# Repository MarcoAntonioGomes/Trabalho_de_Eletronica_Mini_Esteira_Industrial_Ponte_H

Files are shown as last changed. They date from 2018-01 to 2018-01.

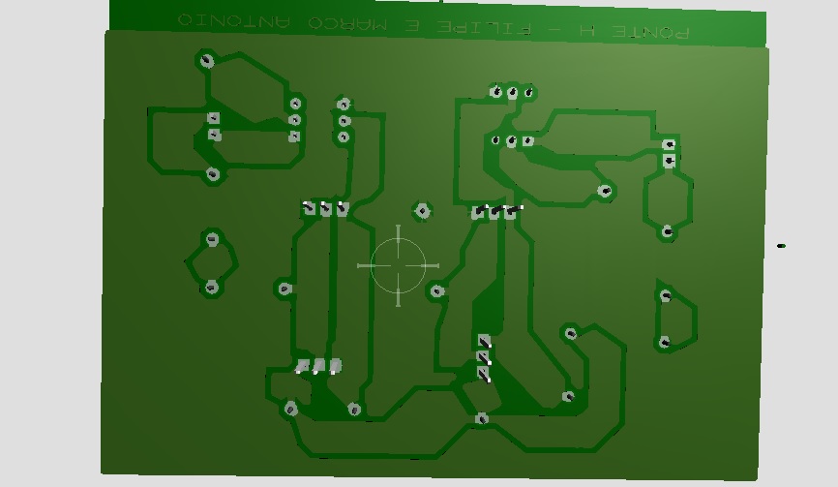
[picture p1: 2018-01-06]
Trilhas 3D.jpg

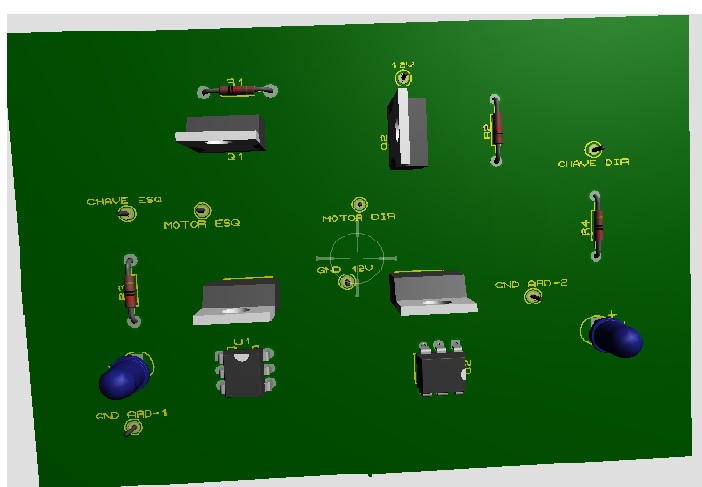
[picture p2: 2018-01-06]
Placa 3D.jpg

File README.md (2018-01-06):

# Trabalho_de_Eletronica_Mini_Esteira_Industrial_Ponte_H
Repositório criado para armazenar os arquivos do Trabalho Final de Eletrônica 2 do curso de Engenharia de Computação - 5º Período - 1º Semestre de 2017 - Confecção de uma Mini Esteira Industrial - com uso de Transistores MOSFETs, Arduíno, placa de circuito impresso, motor dentre outros componentes.

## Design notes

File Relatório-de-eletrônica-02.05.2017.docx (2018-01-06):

O INSTITUTO FEDERAL DE EDUCAÇÃO, CIÊNCIA E TECNOLOGIA DE MINAS GERAIS

FILIPE SOARES,

MARCO AURÉLIO MONTEIRO LIMA

ELETRÔNICA II:

PONTE H

BAMBUÍ

2017

Objetivo:

Verificar experimentalmente o funcionamento da ponte H com motor, utilizando o MOSFET canal N e canal P.

1 – Introdução

Mosfet canal N

MOSFET é um transistor de efeito de Campo de Óxido de Metal Semicondutor.

Figura 1: estrutura simplificada do Mosfet;

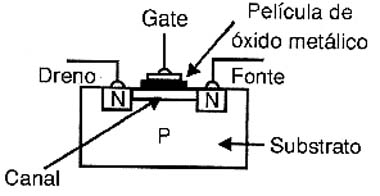
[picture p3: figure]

Uma fina película de óxido de metal isola a região de comporta da região do canal que liga o dreno à fonte. Dependendo da polaridade dos materiais semicondutores podemos ter MOSFET de canais N ou P, conforme a figura 2.

Figura 2: Tipos de MOSFET;

Para usar o transistor de efeito de campo de canal N o circuito básico é mostrado na figura 3.

Figura 3: configuração básica e características do mosfet canal n;

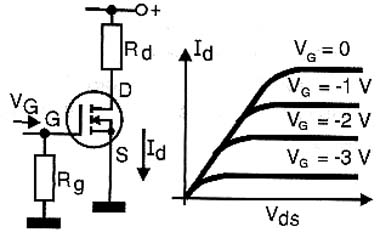
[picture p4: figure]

Com uma tensão nula de comporta a corrente de dreno tem um valor que depende da tensão de alimentação até o ponto de saturação. Para cortar a corrente de dreno a comporta deve ficar negativa em relação a tensão de fonte. Tanto mais negativa ela fica menor é a corrente que pode fluir entre o dreno e a fonte conforme mostra o gráfico junto à figura. Observe que estas curvas são bastante semelhantes as obtidas com válvulas (principalmente os tipos pêntodo) e que polarizando o componente na sua região linear ele se torna um excelente amplificador de sinais.

Mosfet canal P

Os MOSFETs de canal P também são dispositivos que tem uma estrutura no modo de enriquecimento.

Figura 4: MOSFET canal P;

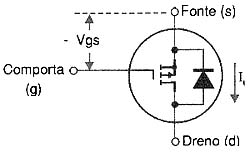
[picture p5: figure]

Uma tensão entre a comporta (gate) e a fonte (source) leva o dispositivo a conduzir a corrente entre a fonte (source) e o dreno (drain).

As diferenças em relação aos dispositivos de canal N estão justamente na polaridade da tensão que deve ser aplicada à comporta e no sentido da corrente que circula através do dispositivo.

Como no caso de transistores bipolares NPN e PNP, podemos dizer que os MOSFETs de Canal N e de Canal P são "complementares".

Ponte H

É um circuito de eletrônica de potência do tipo chopper de classe E (um chopper classe E converte uma fonte fixa de corrente continua fixa em uma tensão de corrente continua variável abrindo e fechando diversas vezes), e, portanto, pode determinar o sentido da corrente, a polaridade da tensão e a tensão em um dado sistema ou componente.

Seu funcionamento dá-se pelo chaveamento de componentes eletrônicos usualmente utilizando do método de PWM para determinar além da polaridade, o módulo da tensão em um dado ponto de um circuito.

Tem como principal função o controle de velocidade e sentido de motores DC escovados, podendo também ser usado para controle da saída de um gerador DC ou como inversor monofásico.

Figura 5: Circuito de uma ponte H;

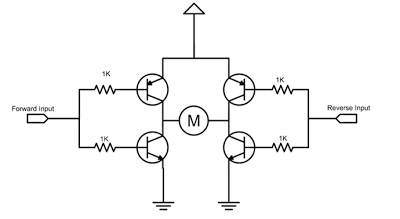
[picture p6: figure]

2 – Lista de matérias

Nesta prática foi utilizado o software Proteus, para simulação do MOSFET com ponte H.

3 – Desenvolvimento

A ponte H é um sistema utilizado para fazer com que o motor gire em dois sentidos. Nesta prática foi utilizado o software Proteus para simular a rotação de um motor utilizando Mosfet.

Imagem 1- Ponte H com Mosfet e JFet

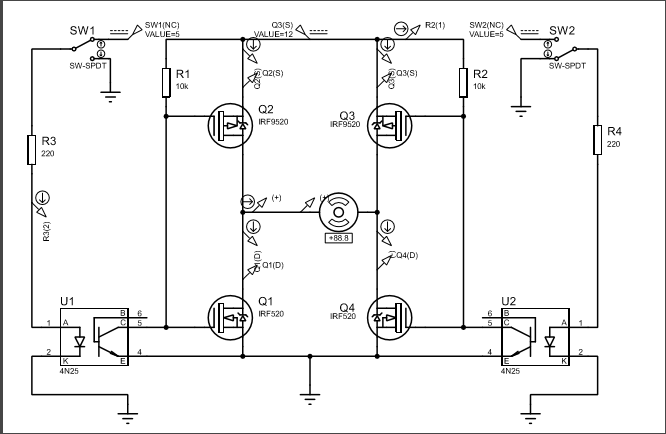
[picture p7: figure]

A figura 1 representada cima representa o circuito simulado no proteus.

Existem duas chaves no circuito, Sw1 e Sw2. Estas representam a introdução de duas fontes de 5V no circuito. Quando Sw1 está ligada e Sw2 está desligada, temos uma tensão de 12 volts no Q2. Como este possui uma tensão no gate, surge uma corrente no dreno, está corrente percorre o caminho até o motor, passando por ele e depois saindo pelo Q2 e assim indo para o terra. Está corrente ao circular neste sentido, faz com que o motor gire no sentido horário. A corrente que sai de Q2 não desce para o Q1, devido a este não possuir uma tensão suficiente no gate, logo não a fluxo de corrente pelo dreno, o mesmo ocorre com o Q3.

Imagem 2 – Chave Sw1 ligado e Sw2 desligado, sentido da corrente

Ligando Sw2 e desligando Sw1, surge uma tensão no gate do M Q3, com isso a tensão de 12V é aplicada no gate e surge assim uma corrente no dreno. Está corrente passa pelo motor, devido ao fluxo de corrente ser contrário ao primeiro estágio citado, o motor rodará em um sentido diferente, ou seja, o sentido anti-horário. A corrente após sair do motor passa por Q1 que também possui uma tensão no gate, assim possibilitando uma passagem de corrente pelo dreno e depois para o terra.

Imagem 3 – Chave Sw2 ligado e Sw1 desligado, sentido da corrente

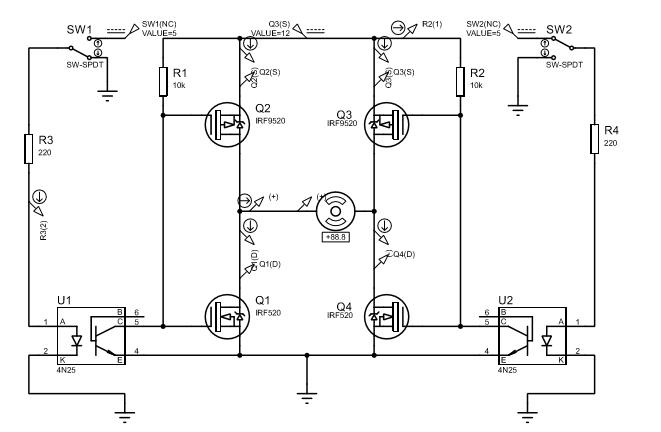
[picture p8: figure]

Com as duas chaves no mesmo sentido, sejam estas desligadas ou ligadas, notamos que o motor não gira devido ao fato que não há uma diferença de potencial que permita aos Mosfet’s possuírem uma tensão no gate, para permitir assim o fluxo de elétrons através do dreno.

O opto-isolador(4N25) é utilizado para minimizar a entrada de ruídos no circuito ou a variação de tensão que possa ocorrer. Como a transmissão de sinal ocorre por meio de uma luz, esta consegue isolar o circuito de qualquer ruído.

Tabela 1 – Posição das chaves e sentido de rotação do motor

Sw1 | Sw2 | Sentido de rotação do Motor
Ligado | Ligado | Parado
Ligado | Desligado | Horário
Desligado | Ligado | Anti-Horário
Desligado | Desligado | Parado

Os resistores R3 e R4 foram utilizados para limitar a corrente que entra nos opto-isoladores. Já os resistores R1 e R2 foram utilizados para que todas a tensão de 12V da fonte VDD ficasse nos Mosfet, de modo que apenas quando a chave estivesse ligada, este ficaria “polarizado”.

Todos os valores dos componentes já foram estabelecidos pelo professor, não havendo cálculos para os valores dos resistores e de nenhum outro elemento.

Foi solicitado pelo professor que elaborasse a seguinte tabela:

Tabela 2- Valores obtidos de tensão e corrente através da posição das chaves

Sw1 | Sw2 | Ro | Im | Vm | Vq1 | Iq1 | Vq2 | Iq2 | Vq3 | Iq3 | Vq4 | Iq4 | N.R
0V | 0V | P | 0A | 0V | 12V | 0A | 12V | 0A | 12V | 0A | 12V | 0A | 0
0V | 5V | Ant.H | 0.49 | 0.11 | 0.11 | 0.5 | 12V | 0A | 12V | 0.52 | 11.8 | 0 | 487
5V | 0V | H | 0.49 | 11.8 | 11.8 | 0 | 12 | 0.49 | 12 | 0 | 0.11 | 0.49 | 487
5V | 5V | P | 0A | 0V | 12V | 0A | 12V | 0A | 12V | 0A | 12V | 0A | 0

Ro- rotação do motor(direção/sentido)

Im-corrente do motor

Vm- tensão do motor

Vq1 e Iq1- tensão e corrente no Mosfet

Vq2 e Iq2- tensão e corrente no Mosfet

Vq3 e I13- tensão e corrente no Mosfet

Vq4 Iq4- tensão e corrente no Mosfet

N.R- rotações por minuto do motor

4 – Conclusão

Portanto foi possível observar o funcionamento de uma chave H de um modo diferente, sem a utilização de quatros chaves, utilizando transistores de chaveamento por tensão. Não foi possível neste relatório obter uma análise dos valores calculados para os valores analisados na simulação, já que não houve cálculos. Foi possível a verificação que o sentido me que a corrente percorre o circuito é o mesmo da rotação do motor, imagens 2 e 3. Nota-se que os valores de corrente são bem pequenos e que quando o circuito está operando, nota-se que a corrente que passa pelo motor a de entrada e saída, são possuem valores iguais. Mesmo sendo uma coisa obvia, já que é a mesma corrente, comprova o sentido que a corrente está fazendo, como também o sentido do motor.

5 – Bibliografia

Disponível em < http://www.sistemaembutido.com.br > acessado em 12/05/2017

Disponível em < http://newtoncbraga.com.br > acessado em 12/05/2017

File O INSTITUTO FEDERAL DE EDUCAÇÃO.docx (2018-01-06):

O INSTITUTO FEDERAL DE EDUCAÇÃO, CIÊNCIA E TECNOLOGIA DE MINAS GERAIS

FILIPE SOARES FERNANDES,

MARCO ANTÔNIO GOMES

TRABALHO DE ELETRÔNICA II:

PONTE H COM MOSFET-ESTEIRA E LIXADEIRA

BAMBUÍ

2017

Sumário

1_ Introdução

2_Motivação

3_Materiais utilizados

4_Desenvolvimento

5_Conclusão

6_Bibliografia

1_INTRODUÇÃO

Ponte H é um termo utilizado para nomear um circuito utilizando chaves que pode modificar dependendo da posição das chaves o sentido de rotação de um motor, o qual é normalmente mais utilizado.

Figura 1- Representação de uma ponte H

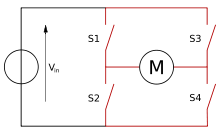
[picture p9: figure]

Como pode-se observar na imagem 1, nota-se que o nome deste tipo de circuito é dado pelo formato que ele possui, e seu funcionamento se dá de acordo com a imagem da figura 2.

Imagem 2 a e b- Fechamento das chaves na ponte H

Temos na figura 2.a o sentido da corrente determinado, quando a chave s1 e a chave s4 estão fechadas, como pode-se ver na imagem, o motor gira no sentido horário, com queda de tensão no sentido anti-horário. Já na figura 2.b, as chaves s2 e s3 estão fechadas e o sentido de rotação é anti-horário e a queda de tensão no sentido horário. Logo, dependendo da maneira se as chaves são posicionadas é possível de selecionar o sentido de rotação do motor.

Uma maneira proposta pelo prof.Caleb em uma aula de laboratório, foi a utilização de mosfets e Jfets no lugar das chaves, para assim conseguir controlar o sentido de rotação do motor.

Mosfet canal N

MOSFET é um transistor de efeito de Campo de Óxido de Metal Semicondutor.

Figura 1: estrutura simplificada do Mosfet;


Uma fina película de óxido de metal isola a região de comporta da região do canal que liga o dreno à fonte. Dependendo da polaridade dos materiais semicondutores podemos ter MOSFET de canais N ou P, conforme a figura 2.

Figura 2: Tipos de MOSFET;

Para usar o transistor de efeito de campo de canal N o circuito básico é mostrado na figura 3.

Figura 3: configuração básica e características do mosfet canal n;


Com uma tensão nula de comporta a corrente de dreno tem um valor que depende da tensão de alimentação até o ponto de saturação. Para cortar a corrente de dreno a comporta deve ficar negativa em relação a tensão de fonte. Tanto mais negativa ela fica menor é a corrente que pode fluir entre o dreno e a fonte conforme mostra o gráfico junto à figura. Observe que estas curvas são bastante semelhantes as obtidas com válvulas (principalmente os tipos pêntodo) e que polarizando o componente na sua região linear ele se torna um excelente amplificador de sinais.

Mosfet canal P

Os MOSFETs de canal P também são dispositivos que tem uma estrutura no modo de enriquecimento.

Figura 4: MOSFET canal P


Uma tensão entre a comporta (gate) e a fonte (source) leva o dispositivo a conduzir a corrente entre a fonte (source) e o dreno (drain).

As diferenças em relação aos dispositivos de canal N estão justamente na polaridade da tensão que deve ser aplicada à comporta e no sentido da corrente que circula através do dispositivo.

Como no caso de transistores bipolares NPN e PNP, podemos dizer que os MOSFETs de Canal N e de Canal P são "complementares".

Ponte H com Mosfet’s

A figura 3, nos representa o esquema de uma ponte H utilizando Mosfet’s.

Figura 3- Ponte H, com Mosfet’s e Jfet’s


A figura 3 representada cima representa o circuito simulado no proteus.

Existem duas chaves no circuito, Sw1 e Sw2. Estas representam a introdução de duas fontes de 5V no circuito. Quando Sw1 está ligada e Sw2 está desligada, temos uma tensão de 12 volts no Q2. Como este possui uma tensão no gate, surge uma corrente no dreno, está corrente percorre o caminho até o motor, passando por ele e depois saindo pelo Q2 e assim indo para o terra. Está corrente ao circular neste sentido, faz com que o motor gire no sentido horário. A corrente que sai de Q2 não desce para o Q1, devido a este não possuir uma tensão suficiente no gate, logo não a fluxo de corrente pelo dreno, o mesmo ocorre com o Q3.

Imagem 4 – Chave Sw1 ligado e Sw2 desligado, sentido da corrente

Ligando Sw2 e desligando Sw1, surge uma tensão no gate do M Q3, com isso a tensão de 12V é aplicada no gate e surge assim uma corrente no dreno. Está corrente passa pelo motor, devido ao fluxo de corrente ser contrário ao primeiro estágio citado, o motor rodará em um sentido diferente, ou seja, o sentido anti-horário. A corrente após sair do motor passa por Q1 que também possui uma tensão no gate, assim possibilitando uma passagem de corrente pelo dreno e depois para o terra.

Imagem 5 – Chave Sw2 ligado e Sw1 desligado, sentido da corrente


Com as duas chaves no mesmo sentido, sejam estas desligadas ou ligadas, notamos que o motor não gira devido ao fato que não há uma diferença de potencial que permita aos Mosfet’s possuírem uma tensão no gate, para permitir assim o fluxo de elétrons através do dreno.

O opto-isolador(4N25) é utilizado para minimizar a entrada de ruídos no circuito ou a variação de tensão que possa ocorrer. Como a transmissão de sinal ocorre por meio de uma luz, esta consegue isolar o circuito de qualquer ruído.

Modulação PWN

A modulação PWN é utilizada para se ter um controle na velocidade de motores CC. Controlando-se a largura do pulso gerado, é possível controlar a velocidade de rotação do motor. Isto é feito comparando dois sinais de tensão, um sinal de baixa frequência (referência) e outro de alta frequência (portadora), resultando em sinal alternado com frequência fixa e largura de pulso variável.

2_Motivação

O motivo de termos feito este trabalho, foi devido à como achamos inteligente a utilização de Mosfet’s em vez de chaves para mudarmos a direção de rotação de um motor. Dessa maneira foi possível inverter o sentido de rotação do motor utilizando apenas duas chaves, além de aplicarmos os conceitos obtidos em sala neste trabalho.

3_Matériais utilizados

Software de Simulação Proteus;

2-MOSFET IRF 9530 de canal P;(Foi utilizado esse mosfet pois, não encontramos o 9520 para compra. Através do data sheet buscamos um que seria semelhante).

2-MOSFET IRF 630 de canal N; ;(Foi utilizado esse mosfet pois, não encontramos o 520 para compra. Através do data sheet buscamos um que seria semelhante).

2- Isolador ótico 4N25;

2- Leds vermelhos;

2- Resistores de 10KΩ;

2-Resistore de 220Ω;

Arduíno;

Cabos para conexão dos componentes;

Placa fenolíte 10x15cm;

1-Chaves de três posições;

1-Potênciometro de 100KΩ;

Pregos;

Parafusos;

Lixa;

Motor de impressora;

Madeira MDF;

Cano de PVC;

Estanho;

Ferro de Solda;

Ácido para corrosão da placa;

Bombril;

Papel fotográfico;

Auto CAD;

Serra Tico Tico;

Multímetro;

2 Rolamentos;

Haste de ferro com espiral para colocar parafuso (utilizado como segundo eixo).

4_Desenvolvimento

Figura 4- Ponte H com Mosfet’s e arduíno

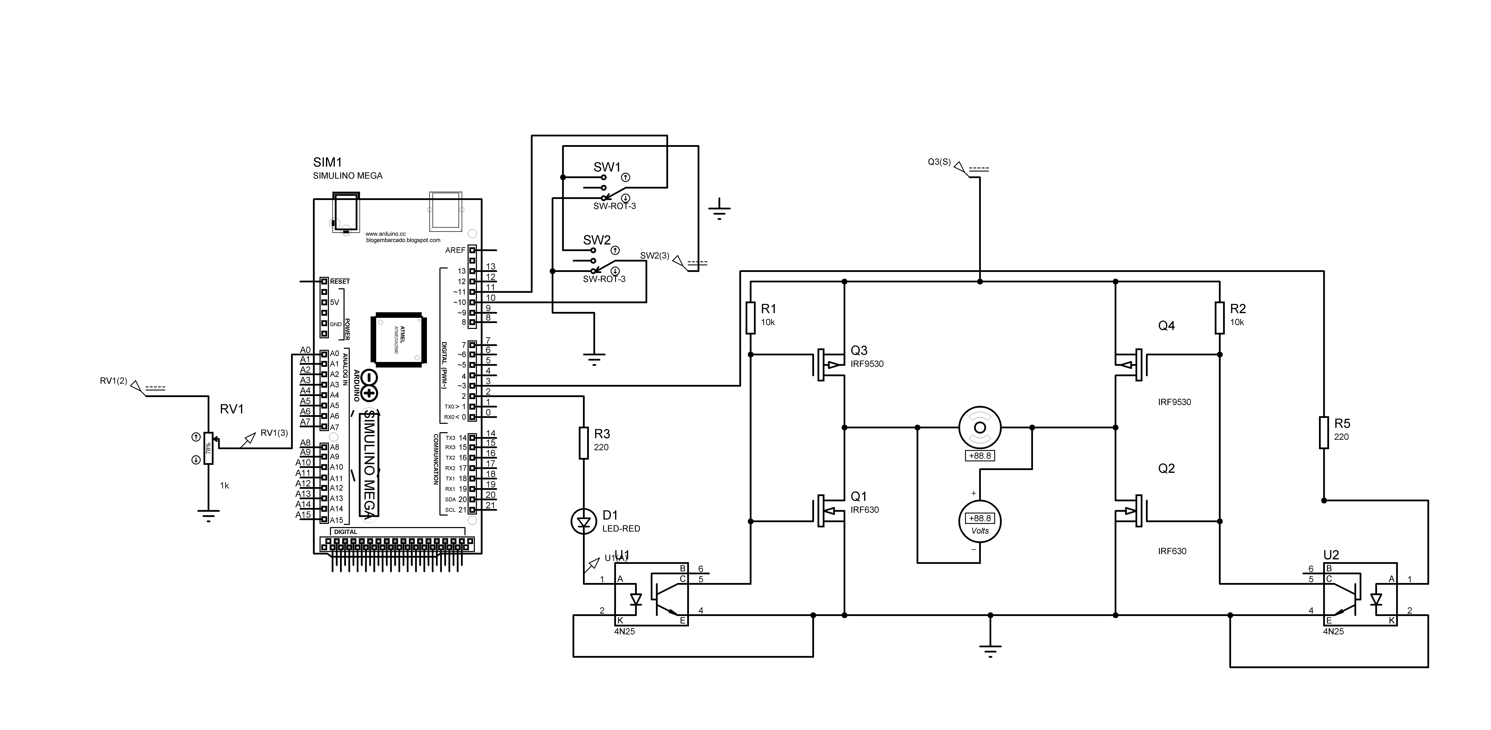
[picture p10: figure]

A figura 4 representa a simulação feita da esteira no proteus. Está esteira/lixadeira utiliza os conceitos apresentado na introdução deste relatório, qual é o sentido da corrente e com os Mosfet’s funcionam. A inserção do arduíno ocorreu devido ao comentário do prof.Caleb, sobre controlarmos a velocidade de movimento desta esteira/lixadeira.

O potenciômetro recebe uma tensão de 5V, este potenciômetro irá controlar a velocidade com que a esteira/lixadeira irá se movimentar. O arduíno possuí uma programação feita para operar este circuito, já que é também necessário saber quais saídas/portas irão operar, já que possui também entradas/saídas analógicas e digitais.

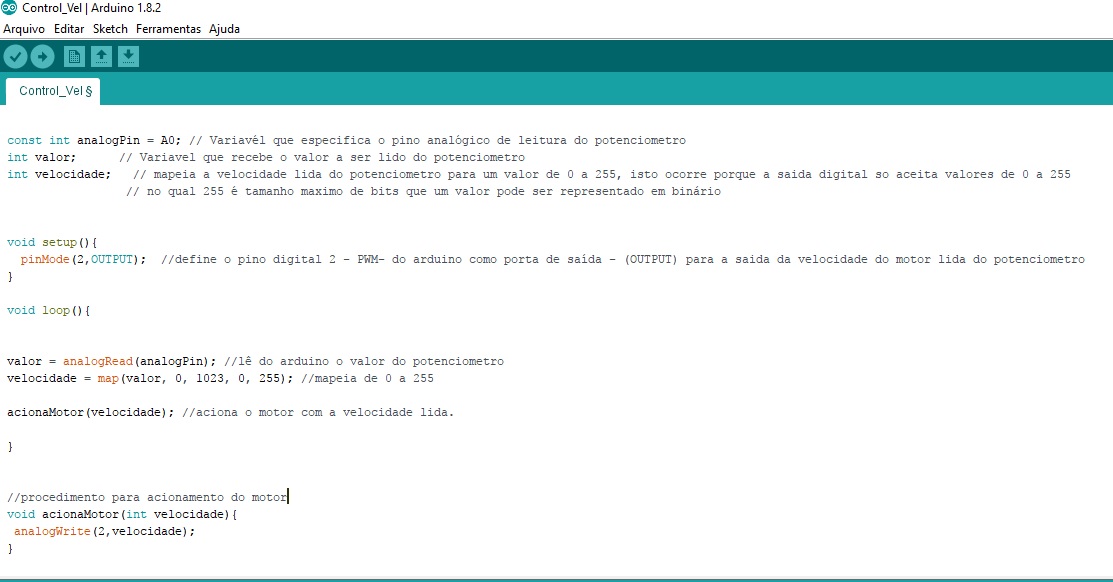
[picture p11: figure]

Imagem 5- Programação arduíno

Como podemos observar nos comentários feitos no programa, o potenciômetro vai em uma porta analógica no arduíno. É necessário também pegar a posição em que o cursor do potenciômetro está, para determinar o nível de tensão da sua saída. Existe uma variável para guardar a velocidade lida pelo potenciômetro, como o potenciômetro está alimentado com uma tensão de 5V, o arduíno pega está tensão e a converte para um intervalo de 0 a 255 bits. Sendo que 0 bits é sem tensão e 255 bits são os 5V.

Na função setup definimos os pinos de saídas do arduíno. Nas outras funções lemos o valor fornecido pelo potenciômetro e acionamos o motor. Este código do arduíno é bem simples e de fácil compreensão.

Sendo este código carregado no arduíno para assim conseguimos fazer a esteira/lixadeira entrar em funcionamento.

Uma coisa que foi modificado no projeto em relação a simulação, é que utilizamos apenas uma chave para ligar e fazer a inversão do motor. Como está chave possui três estágios, optamos pela utilização desta, além de ficar mais apresentável.

Figura 6- Potenciômetro e chave liga/muda sentido de rotação

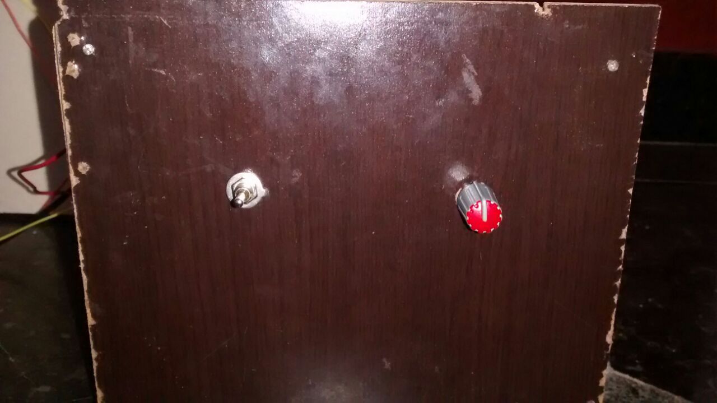
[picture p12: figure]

Como podemos ver na imagem 6, utilizamos apenas uma chave.

Depois de montado o circuito no Proteus, foi feita a montagem deste circuito na protoboard. Pois queríamos verificar se o trabalho estava funcionando antes de soldarmos os componentes.

Montagem Protoboard

Figuras 7- Montagem na Protoboard(a, b e c)

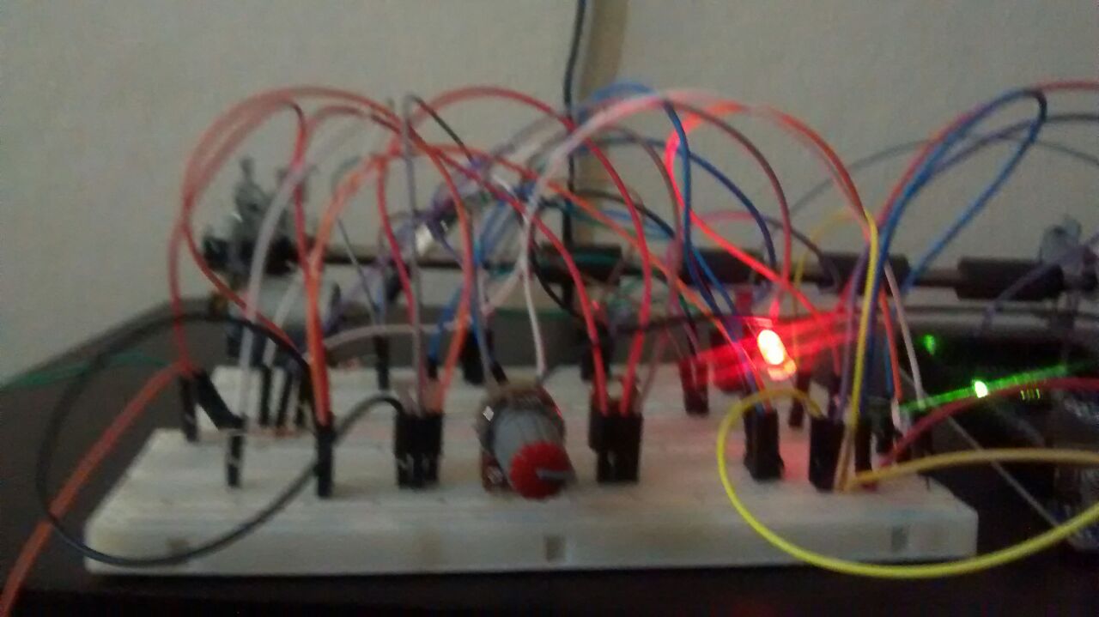
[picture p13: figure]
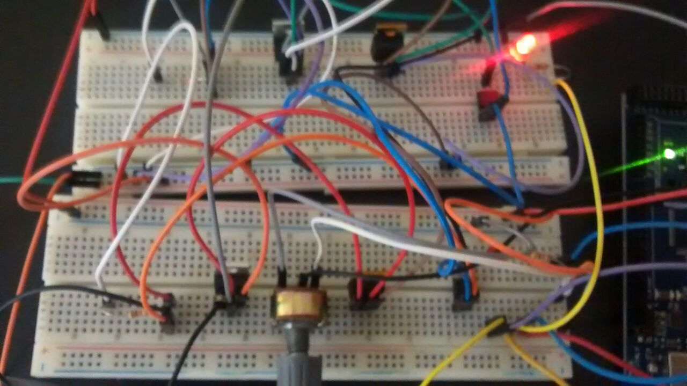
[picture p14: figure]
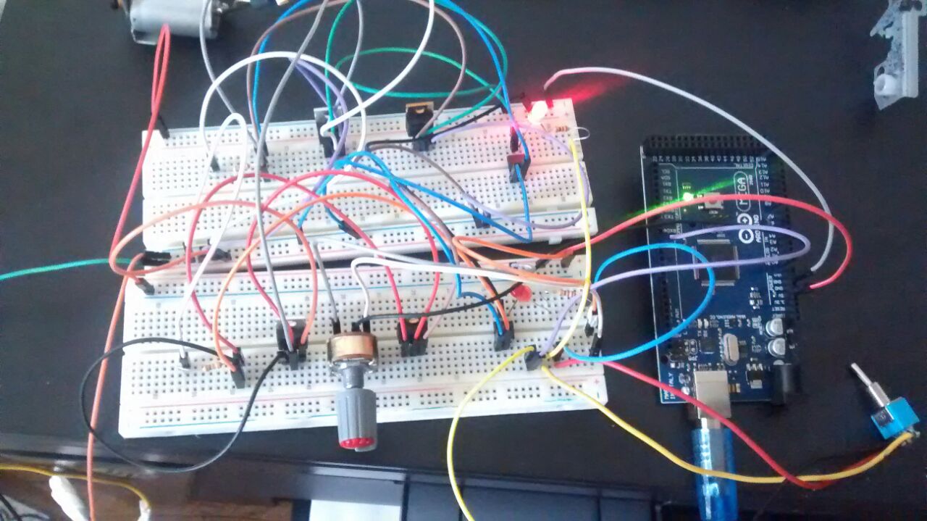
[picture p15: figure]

Está montagem na protoboard foi necessária, pois foi nela que constatamos um erro que não acontecia na simulação. Na figura 4, nota-se que o terra do arduíno é o mesmo da ponte H, é possível observar que na simulação não ocorre nenhum erro. Mas, ao montarmos na protoboard esse mesmo circuito notamos que a ponte H não funcionava. Fomos buscar o porquê na internet e contatamos que deveríamos fazer um terra específico para a protboard.

Como o terra era o mesmo da ponte H, o acoplador ótico, não conseguia isolar o circuito, deixando haver uma grande variação de tensão no circuito, já que o potência era o mesmo. Desta maneira refizemos a simulação no proteus, para depois gerar a impressão. Na figura é possível ver o led aceso, pois este indica o funcionamento do motor. Na figura 4 existem dois leds, cada um representando um sentido de rotação do motor.

Figura 8- Correção da Ponte H no proteus, separação dos terras

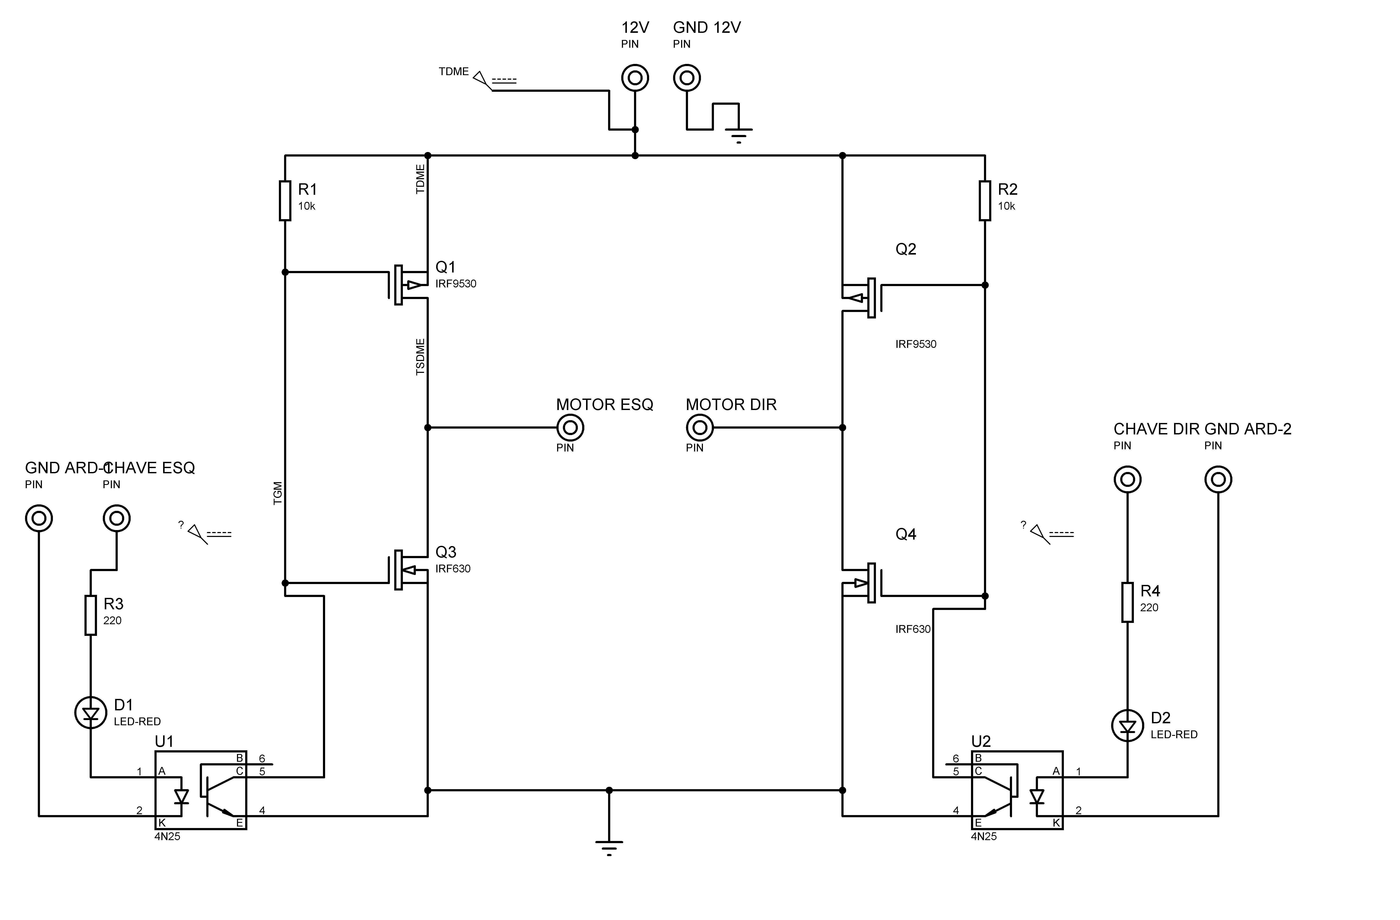
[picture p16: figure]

A figura 8 não possui o arduíno, pois está já representa o modelo do qual iriamos criar o PCB para impressão. Nota-se que o terra do arduíno e da ponte H, não são os mesmos agora. Deve-se sempre fazer a montagem do circuito para depois fazer a solda dos componentes. Mesmo o proteus sendo um programa que tenta se aproximar o máximo ao real, é importante saber que na teoria as coisas são muito mais fáceis de mexer, já na prática sempre temos vários fatores que podem comprometer a prática.

PCB

Depois de feita todas as verificações, foi feito o PCB para impressão das trilhas para corrosão da placa.

Figura 9 – PCB Ponte H/componentes

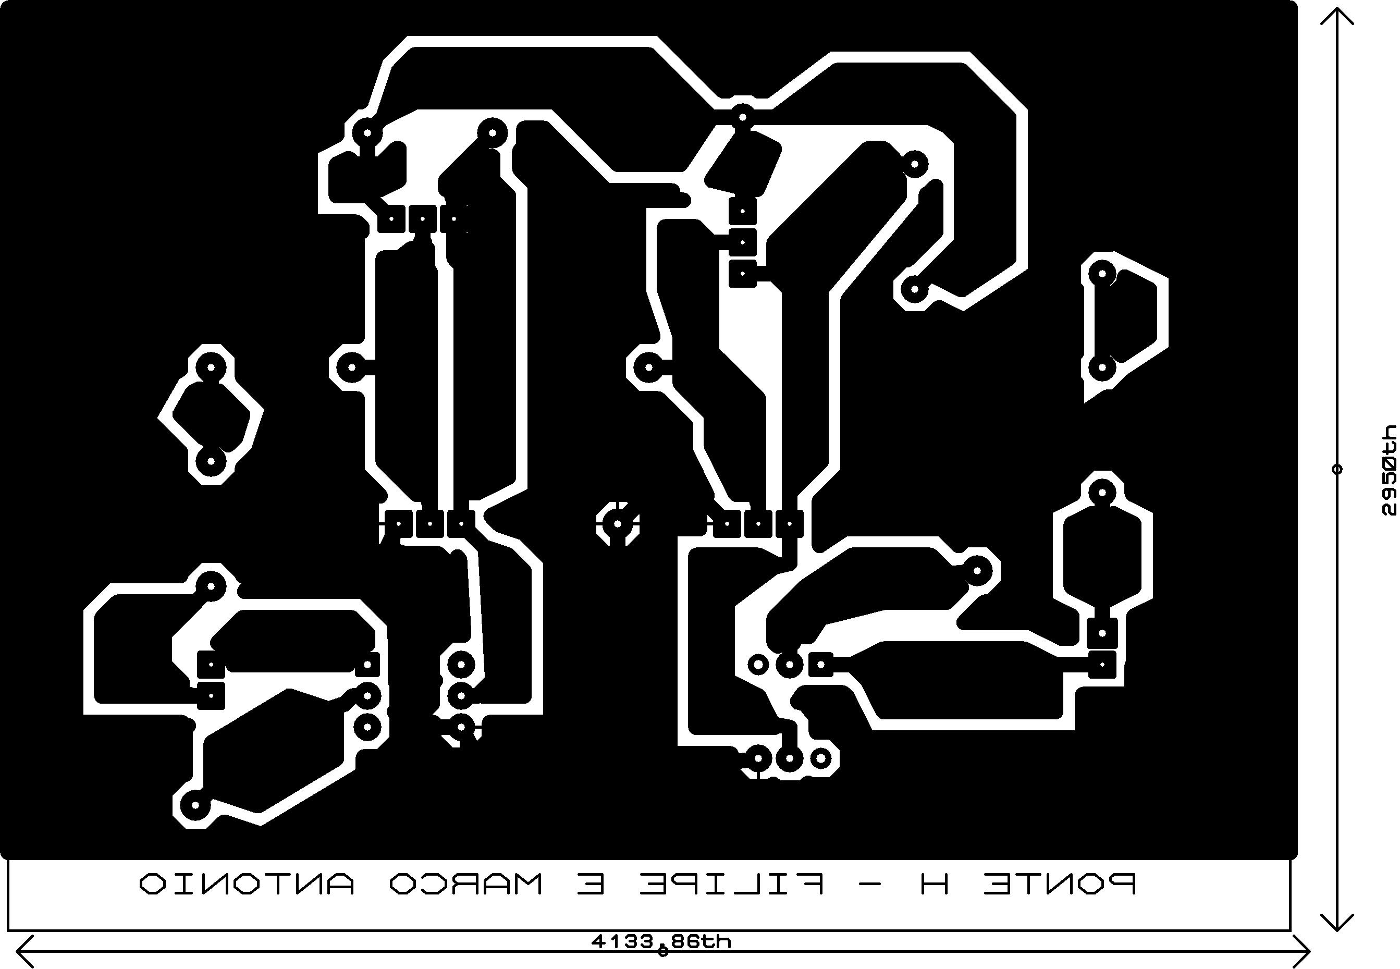
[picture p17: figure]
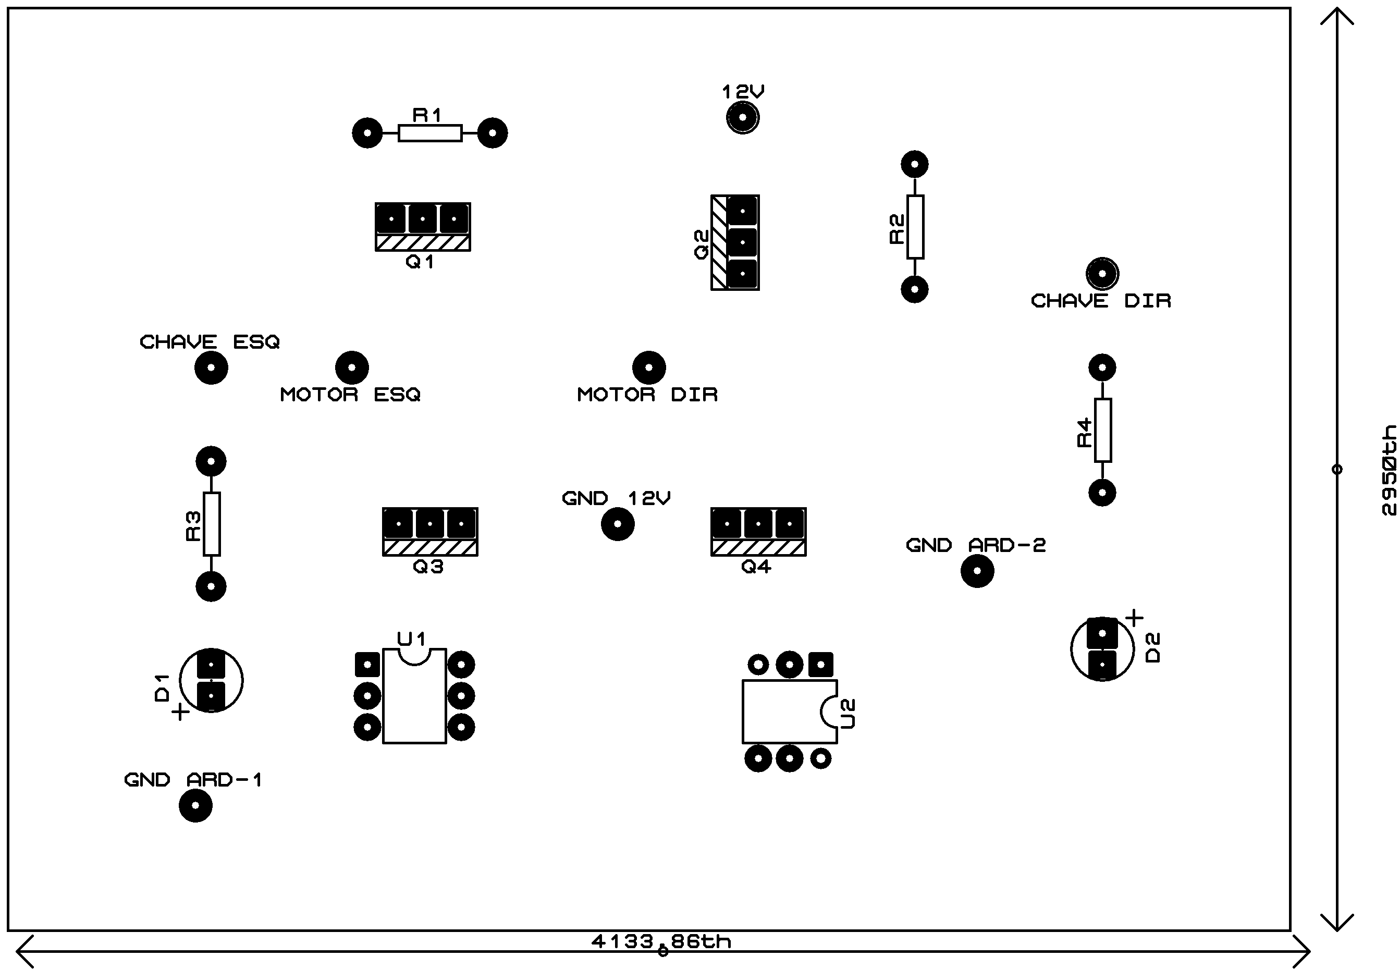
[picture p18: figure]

Figura 10-Placa em 3D


Figura 11- Trilhas placa 3D


O PCB figura 9, nos fornece as trilhas e os locais de solda de cada componente. Essa malha maior é o GND da Ponte H. Este PCB foi impresso, preso a uma placa de fenolite, presa com fita crepe. Antes de grudar o papel a placa é necessário limpa-la, já que pode haver gordura da mão ou até poeira presa a ela. O que dificultaria a passagem da tinta para a placa. Este papel foi aquecido com ferro por um período de 15 minutos, quando foi possível observar a passagem da tinta para a placa iniciamos o processo de corrosão.

Esquecemos de tirar fotos do processo de corrosão, mas, como já havíamos executado este processo em um outro trabalho, este foi rápido e deu certo de primeira. Esperamos mais ou menos uns 30 minutos no ácido.

Confecção da esteira

Para confeccionar a esteira geramos um projeto no auto cad, para esta ser montada na marcenaria do IF-Bambuí. O pedido foi realizado pelo prof.Caleb mas, está confecção não aconteceu e o grupo foi obrigado a montar a esteira/lixadeira. A imagem do projeto está como anexo 1, no final deste trabalho.

Reunimos na sexta (9/06/2017) e no sábado (10/06/2017) no laboratório do lado esquerdo ao laboratório de eletrônica para cortarmos a madeira e montarmos a maquete de acordo com o projeto.

Figura 11 – Esteira/lixadeira

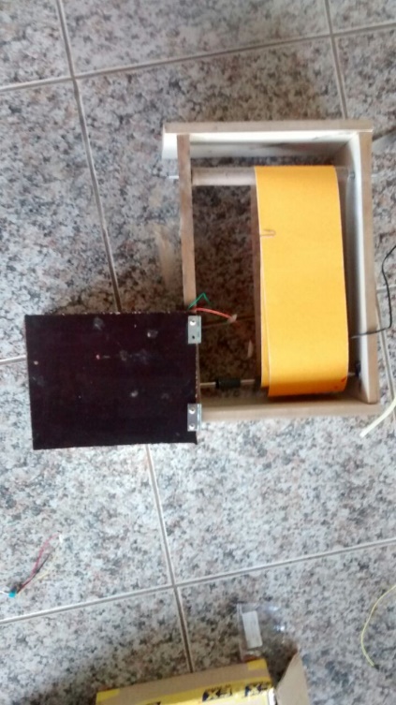
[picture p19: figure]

A figura 11 mostra a esteira/lixadeira finalizada. Está possui dois eixos, um sendo o motor, e o outro é um cano de PVC que possui rolamento em seu interior e no centro destes rolamentos existe uma barra de ferro. Quando o motor roda, a lixa que está em cima é movimentada e está gira o cano, como os rolamentos estão presos ao cano, seu eixo se movimenta ao redor da barra de ferro, no sentido que o motor estiver rodando. O cano foi lixado de modo, que o rolamento ficasse com um pouco para fora, de modo a diminuir o atrito com a parede da esteira/lixadeira. Nota-se que existe uma casinha do lado da esteira, está casinha é onde o circuito montado e o motor da esteira irão ficar. Está casinha possui uma tampa, para proteger o circuito e o motor.

Todas as peças de madeira foram parafusadas, foi feito um furo menor com uma broca de circunferência menor que os parafusos, para depois estes serem inseridos. Estas peças de madeira foram cortadas com a serra tico tico.

Figura 12 – Casinha com motor

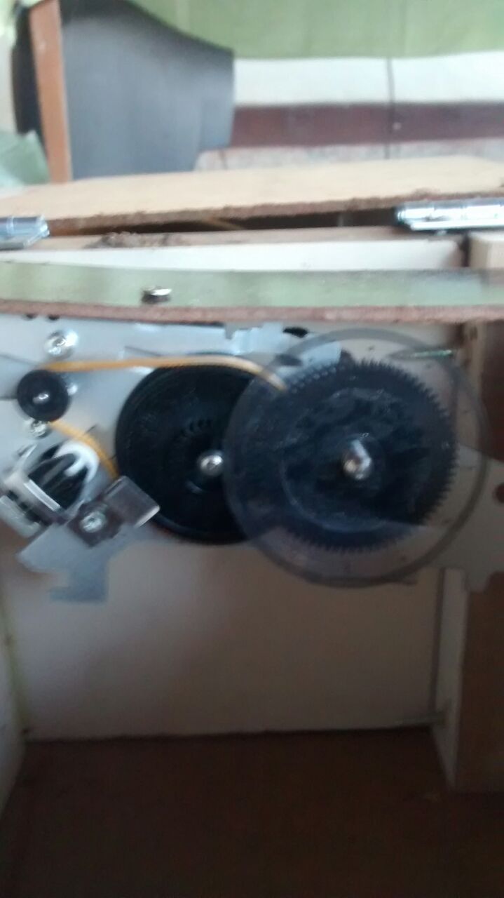
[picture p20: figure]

Figura 13- Casinha com o circuito dentro

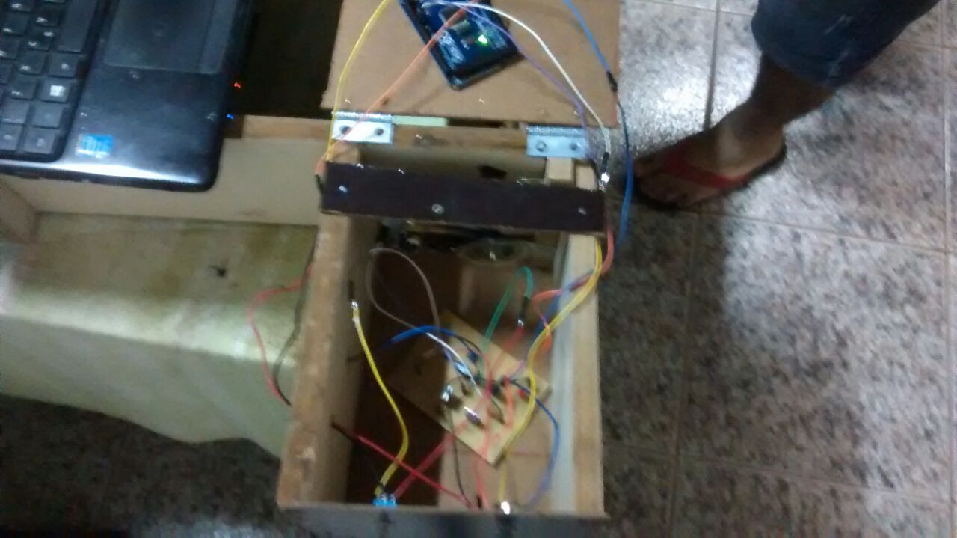
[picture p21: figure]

Solda dos componentes na placa

Depois de corroída a placa, o lugar das pernas dos componentes foi furado e depois todos os componentes foram soldados. O auxílio da localização de cada componente se deu por causa do 3D da figura 10. O grupo também esqueceu de tirar fotos da solda dos componentes.

Finalização da esteira/lixadeira

Como observado na figura 6, apenas foi deixado de fora da casinha onde está a placa do circuito, o potenciômetro e a chave de mudança de direção. Deste modo é possível ver apenas a esteira/lixadeira, deixando o trabalho mais limpo visualmente.

Figura 14- Esteira/Lixadeira Finalizada

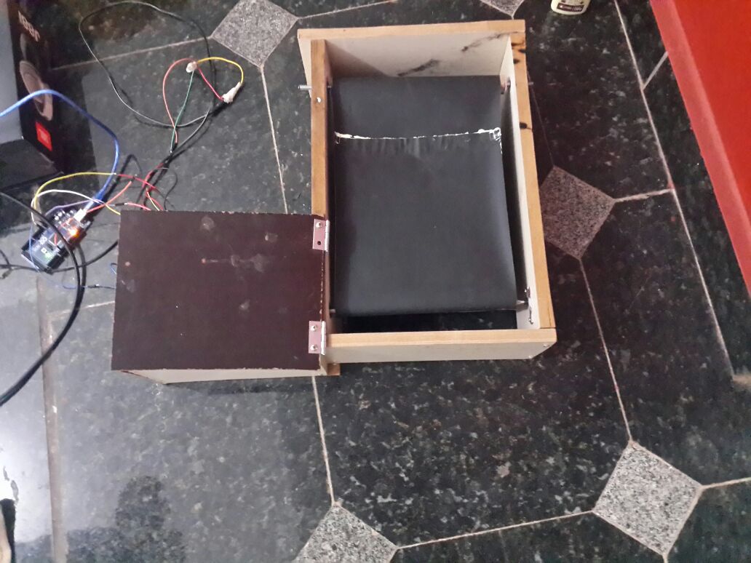
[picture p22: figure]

Como podemos observar na figura 14, a lixa utilizada é uma lixa d’agua 3M. Está é uma lixa fina de fácil maleabilidade, permitindo assim que está se encaixe com mais facilidade sobre os eixos. O ruim de desta lixa, é que ela é vendida apenas em folhas de 23cm, por isso iremos utilizar 6 folhas desta lixa.

A união destas folhas, foi feita com cola madeira. A parti da lixa ficará para cima e a parte lisa, ficará ao redor dos eixos, ou seja, para baixo.

Figura 15- Colando as Lixas

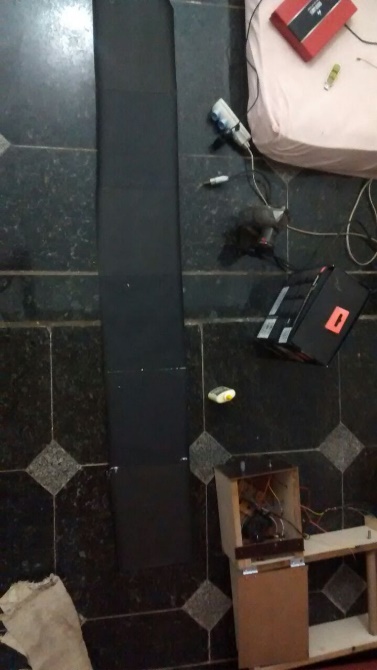
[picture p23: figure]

Depois de colocada a lixa sobre os rolamentos, a esteira/lixadeira está pronta, para funcionamento. Foi efetuado a gravação de um vídeo do primeiro funcionamento da esteira. Este vídeo será apresentado no dia da apresentação deste trabalho.

Tabela 1 – Valores de tensão e corrente no motor

| Valor Medido | Valor Simulado
Tensão(V) | 11,6V | 11,5V
Corrente(A) | 0,6A | 0,48A

Nota-se que os valores obtidos não foram iguais, mas, os valores medidos estão bem próximos dos valores simulados.

5_Conclusão

A ponte H é muita utilizada para controlar o sentido dos motores, neste trabalho utilizamos aplicação de mosfet’s em vez de chaves na inversão do sentido de rotação do motor. Optamos por este trabalho, pois estávamos estudando estes componentes na matéria de eletrônica 2, como também ficamos impressionados na prática com a possibilidade de utilização deste componente.

Em primeira instância houve um problema na hora de comprar os componentes pois, como tivemos uma prática já utilizando Mosfet’s para controle do motor, utilizávamos 4 mosfet’s, dois 9520 e dois 520. Na loja eletrodex, não havia disponibilidade destes componentes, por isso foi necessário consultar o data sheet destes e verificar um mosfet que se assemelhasse a estes. Através desta consulta, obtivemos os mosfet’s utilizados neste trabalho, que podem ser consultados no item materiais gastos.

A introdução do arduíno e do controle de velocidades, aconteceu devido a um pedido realizado pelo professor Caleb. É necessário entender que existe uma programação feita no arduíno para o controle da velocidade do motor. A modulação PWM é utilizada neste trabalho, onde esse controla a largura do pulso da tensão. Já o potenciômetro é alimentado com uma tensão de 5V, o arduíno lê está tensão e a transforma em uma escala de 0 a 255bits. De acordo com o posicionamento do seletor do potenciômetro, é lida uma determinada tensão e está convertida em um determinado valor.

A utilização deste controle de velocidade, foi de suma importância para o grupo, já que este trabalho não se focou apenas em construir uma esteira/lixadeira, houve uma união entre a programação e a eletrônica, tornando este trabalho mais consistente e mais gratificante para o grupo.

A simulação no Proteus é de suma importância, pois está fornece uma base sobre os valores de tensão e corrente que irão circular nos componentes, como também se existe algum erro no projeto inicial. Claro, que nem sempre o Proteus fornecerá um resultado 100% preciso, já que a teoria é um pouco diferente da prática. Mas, este resultado inicial, é de sua importância para construção do projeto, pois, nunca devemos partir direto para a construção da placa, já que não temos uma certeza se o projeto está certo.

O principal problema que obtivemos no projeto, foi na montagem na protoboard. Pois, não sabíamos que por causa do acoplador-ótico os terras do circuito e do arduíno deveriam ser diferentes. Graças a essa montagem de verificação do circuito na protoboard, foi possível vermos este pequeno defeito, entendermos e no esquema para imprimir da placa, separarmos os terras.

A parte de impressão, corrosão e solda dos componentes, foi bem fácil de se fazer, já que havia um bom tempo até a entrega deste trabalho, o que fez com que todas as etapas fossem feitas com calma. Já a parte de corte das peças de madeira, foi realizada no laboratório do prédio de eletrônica pelo próprio grupo. O corte foi realizado seguindo o anexo 1 deste relatório. Este anexo serviria como um esquema para que a esteira/lixadeira foi feita pela marcenaria, houve o pedido realizado pelo professor Caleb mas, está não foi executada.

O motor utilizado neste trabalho é um motor de impressora de 12V, que foi fornecido pelo professor Francisco. Como a lixa utilizada é bem maleável, este motor é suficiente para movimentar está lixa sem esforço nenhum.

Os valores obtidos de tensão e corrente da simulação e da medição foram bem parecidos, mostrando que os valores corresponderam com os esperados.

Tiramos deste trabalho um aprendizado muito grande, tanto na eletrônica como na programação de arduíno. Como não havíamos utilizado um arduíno antes, foi de suma importância o emprego deste no trabalho. Aprendemos também um pouco de marcenaria, além também de revisarmos o auto cad, para montar o esquema do projeto a esteira/lixadeira.

6_Bibliografia

https://pt.wikipedia.org/wiki/MOSFET

http://labdegaragem.com/profiles/blogs/tutorial-conhe-a-e-utiliza-mosfets

http://www.alldatasheet.com/view.jsp?Searchword=IRF9530

http://www.microsofttranslator.com/bv.aspx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

http://maxwellbohr.com.br/downloads/robotica/mec1000_kdr5000/tutorial_eletronica_-_montagem_de_uma_ponte_h.pdf

https://www.youtube.com/watch?v=7Gt6eZv6kfE

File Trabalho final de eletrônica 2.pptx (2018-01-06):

## Trabalho final de eletrônica 2

Confecção de mini esteira controlável utilizando ponte h
Filipe Soares e marco antônio

## Funcionamento da ponte h


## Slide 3

## Mosfets E Seus Funcionamentos


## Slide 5


## Ponte h utilizando mosfets


## modulação por largura de pulso - pwm

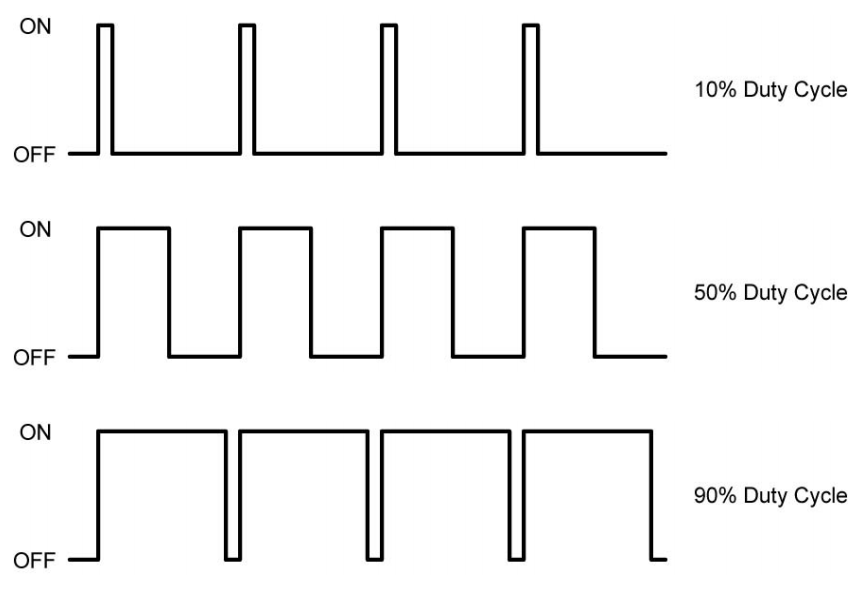
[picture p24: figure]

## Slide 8

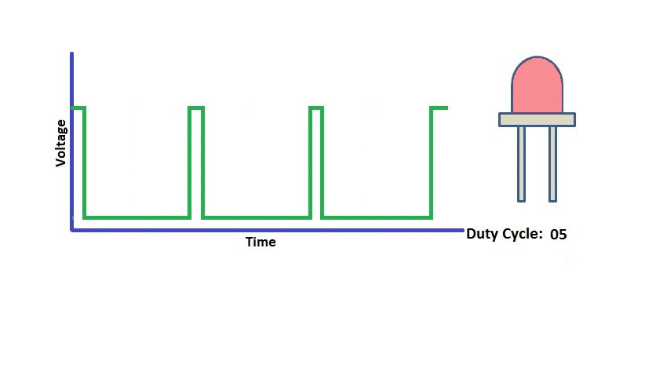
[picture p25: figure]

## Objetivo do trabalho

- Desenvolver uma esteira controlável utilizando os conceitos aprendidos em sala de aula a respeito do uso de Ponte-H e MOSFETs combinado com a utilização de outras técnicas, sendo estas baseadas no uso do arduíno.

## Materiais utilizados

- 1-Potênciometro de 100KΩ
- Pregos
- Parafusos
- Lixa
- Motor de impressora
- Madeira MDF
- Cano de PVC
- Estanho
- Ferro de Solda
- Ácido para corrosão da placa
- Bombril
- Papel fotográfico

- Software de Simulação Proteus
- 2-MOSFET IRF 9530 de canal P
- 2-MOSFET IRF 630 de canal N
- 2- Isolador ótico 4N25
- 2- Leds vermelhos
- 2- Resistores de 10KΩ
- 2-Resistore de 220Ω
- Arduíno
- Cabos para conexão dos componentes
- Placa fenolíte 10x15cm
- 1-Chaves de três posições

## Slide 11

- Auto CAD;
- Serra Tico Tico;
- Multímetro;
- 2 Rolamentos;
- Haste de ferro com espiral para colocar parafuso (utilizado como segundo eixo).

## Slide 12


DESENVOLVIMENTO

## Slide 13


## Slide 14


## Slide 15

Correção dos imprevistos


## Vídeo do teste na protoboard

## CONFECÇÃO DA PLACA DA PONTE H


## Vídeo após conclusão da placa

## Confecção da esteira

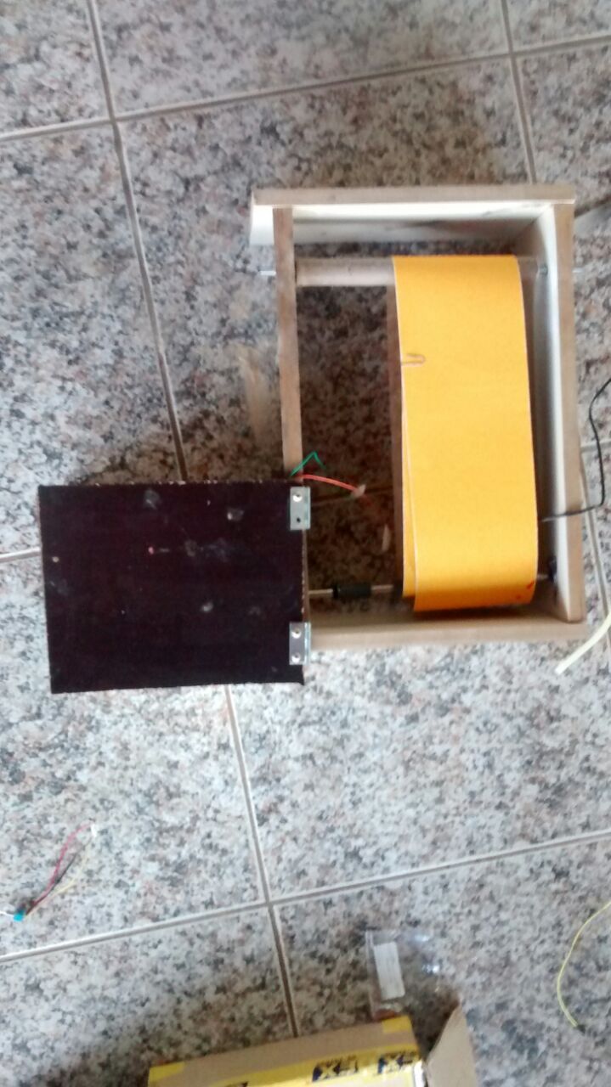
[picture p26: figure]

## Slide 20


## Vídeo após confecção da esteira

## Esteira Concluída


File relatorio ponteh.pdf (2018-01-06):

IFMG-Campus Bambuí

Laboratório de Eletrônica 2

Nomes: Marco Antônio Gomes e Lucas Mariano Vieira

Data: 11/05/2017

Professor: Calebe Giaculi Júnior

Ponte H com MOSFETs

Objetivo: Verificar experimentalmente o funcionamento de MOSFET como chave e o funcionamento da Ponte H para controle de motor DC.

INTRODUÇÃO

MOSFET são transistores de efeito de campo, podem ser tipo depleção ou intensificação. Para cada tipo há transistores de canal-p e canal-n. Um MOSFET é um dispositivo de três terminais como representado na figura 1.

Figura 1: Transistores MOSFET canal-p e canal-n.


Assim como outros transistores, MOSFETs podem ser utilizados como chaves quando polarizados corretamente.

Considerando a curva característica de tensão Vgs em um MOSFET de intensificação na figura 2, podemos escolher dois pontos de operação nesta curva. Primeiro um ponto onde temos que Vgs=0 e outro ponto como uma tensão Vgs qualquer positiva acima de Vth.

Figura 2: Curva característica Transistor MOSFET tipo intensificação canal-n.


No primeiro ponto temos que a corrente no dreno Id=0 A. No segundo ponto porem, temos que Id é diferente de zero. Se a tensão Vgs for suficientemente alta em relação à tensão de limiar Vth, o MOSFET se encontrará na região de saturação. Nesta região podemos aproximar que a tensão dreno fonte Vds=0 V e o MOSFET conduzirá como se fosse um curtocircuito. Assim temos o transistor operando como uma chave que pode ser ligada e desligada.

A ponte H é um dispositivo que pode ser utilizado para controlar voltagem aplicada sobre um motor permitindo controlar a direção da rotação e a velocidade do motor. A figura 3 apresenta um exemplo de ponte H. Pontes H podem ser construídas com vários tipos de dispositivos como relés, chaves mecânicas ou Transistores.

Figura 3: Ponte H como motor.


A ponte H é formada for 4 chaves como indicado na figura 3. Quando as chaves S1 e S4 são fechadas a corrente flui da esquerda para a direita pelo motor. Digamos que o motor gira em sentido horário quando isso ocorre. Se abrirmos as chaves S1 e S4 e fecharmos as chaves S3 e S2, podemos notar que a corrente fluirá na direção oposta e o motor inverterá a sua direção de rotação. A figura 4 apresenta os modos de operação descritos.

Figura 4: Operação Ponte H.


DESENVOLVIMENTO

Materiais Utilizados

Para a realização do experimento foi utilizado um computador como o software de simulação Proteus.

Atividades e Resultados

Para o experimento foi construído dentro do software de simulação Proteus o circuito de Ponte H apresentado na figura 5, utilizando MOSFETs tipo intensificação como chaves.

Figura 5: Ponte H com MOSFET.


O circuito construído utiliza o componente motor-dc do Proteus como a carga para o circuito. Este componente consegue simular a inercia de um motor real, assim após ser ligado, o motor leva um dado tempo para alcançar a rotação máxima para a dada polarização.

Também pode se notar o uso de opto-acopladores no circuito, eles isolam o circuito de acionamento do circuito de carga do motor para impedir que ruídos gerados pelo motor interfiram com a operação da ponte H.

Quando o circuito é simulado, temos que quando a chave SW1 é colocada na posição de 5V e SW2 é colocada na posição de 0V, os transistores Q3 e Q2 passam a conduzir, pois são polarizados corretamente. Q1 e Q4 são desligados. Assim temos que o motor começa a girar em sentido horário. Se invertermos as posições das chaves, o motor passa a girar em sentido antihorário.

Depois dentro da simulação medimos a rotação, tensão e corrente do motor, e as tensões Vgs, Vds e Id do transistor Q1 para todas as combinações de posições das chaves SW1 e SW2. Os resultados obtidos foram registrados na tabela 1.

Tabela 1: Resultados coletados.

SW1 | SW2 | Rotação | Imotor | Vmotor | VGSQ1 | IDQ1 | VDSQ1
0V | 0V | 0 | 0A | 0V | 12V | 0A | 0V
0V | 5V | -487 | 0.48A | -11.7V | 12V | 0.49A | 0.11V
5V | 0V | 487 | 0.49A | 11.7V | 0.21V | 0A | 11.8V
5V | 5V | 0 | 0A | 0V | 0.21V | 0A | 12V

Após coletarmos os dados podemos perceber que a ponte somente conduz quando as chaves SW1 e SW2 estão em posições opostas. Assim como descrito podemos inverter a rotação do motor fazendo os ajustes corretos nas posições das chaves. Quanto ao transistor Q1, podemos perceber que ele se encontra saturado quando SW1 está em 0V, pois com isso a tensão aplicada a sua porta é igual a 12 V, logo temos Vgs tendendo a 12V, logo Q1 conduz. Assim como mencionado anteriormente a tensão Vds tende a zero quando o transistor se encontra em saturação.

CONCLUSÃO

As atividades experimentais foram realizadas com sucesso. Conseguimos montar o circuito da ponte H dado dentro do software de simulação Proteus e observar a operação da mesma quando manipulávamos as chaves SW1 e SW2.

Além da operação do motor DC conectado a ponte H, também se observou o comportamento de um dos transistores presentes na ponte. Conseguimos observar que seu comportamento se enquadra com bastante fidelidade ao modelo de um MOSFET operado com saturação.

Quando o MOSFET se encontra neste regime, o seu comportamento se aproxima do comportamento de uma chave, podendo estar desligado, não permitindo a passagem de corrente, ou ligado permitindo a passagem de corrente com praticamente nenhuma resistência.

Através da simulação conseguimos observar esse comportamento na prática dentro do contexto do funcionamento de uma ponte H. Uma das muitas aplicações de um MOSFET.

REFERÊNCIAS

Boylestad L. R.; Nashesky L., Dispositivos Eletrônicos e Teoria de Circuitos, 11º ed., São Paulo, Pearson, 2013.

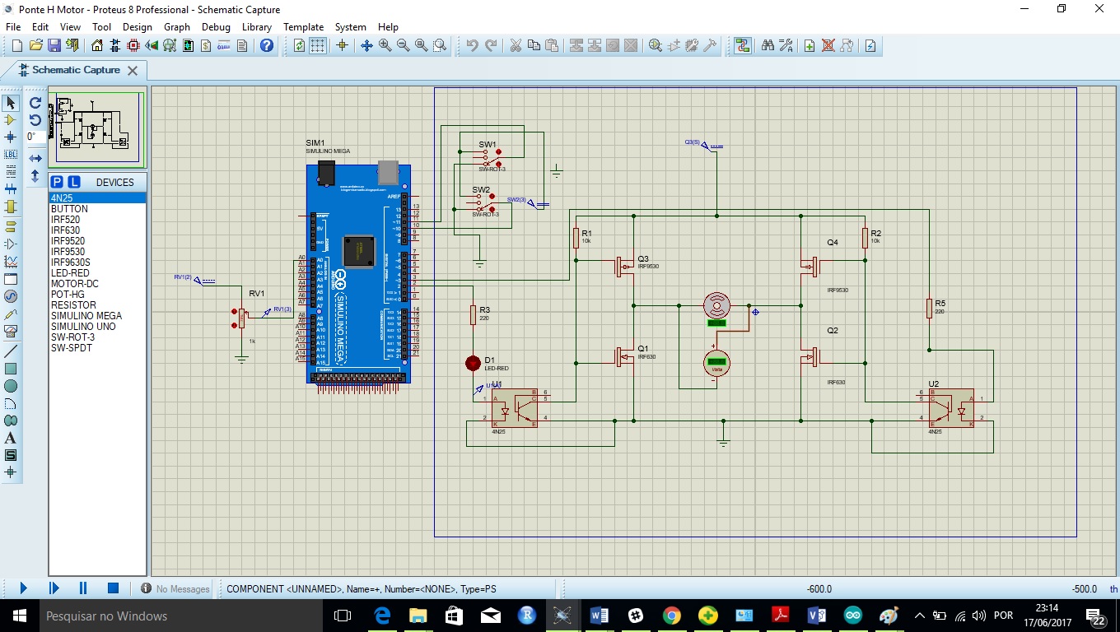
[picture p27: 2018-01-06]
Simulação Ponte H Arduino.jpg

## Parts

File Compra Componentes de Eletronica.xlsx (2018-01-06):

Planilha de Compra Componentes de Eletrônica
Marco Antonio e Felipe
Quant | Descrição | Preço | Total
6 | MOSFETS IRF 9530 Canal p | R$2.48 | R$14.88
6 | MOSFETS IRF 630 Canal N | R$2.81 | R$16.86
4 | Isolador ótico 4N25 | R$0.94 | R$3.76
1 | Borne Vermelho | R$1.40 | R$1.40
1 | Borne Preto | R$1.40 | R$1.40
4 | Leds Vermelho | R$0.23 | R$0.92
4 | Resistor de 220 | R$0.08 | R$0.32
4 | Resistor de 10K | R$0.08 | R$0.32
1 | Conector Para o Arduino | R$3.75 | R$3.75
3 | Placa Fenolite 10x15 Cm | R$3.77 | R$11.31
2 | Sensor De Movimento | R$14.95 | R$29.90 | <- Valor C\ Frete Incluso
1 | Potenciômetro de 1 K | R$1.35 | R$1.35
1 | Potenciômetro de 100 K | R$1.45 | R$1.45
2 | Chave para inverter o giro e desligar o motor | R$2.97 | R$5.94
2 | Knob Vermelho | R$2.14 | R$4.28 | Valores a pagar Marco e Filipe Soares
 |  | Sub Total | R$97.84 | R$48.92 | Valor a pagar pra cada
 |  | C\Frete | R$104.68 | R$52.34 | Com Frete
Filipe Andrade
 |  |  |  | Valor a Pagar, Filipe C\ Frete
2 | Transistor MOSFET IRF630N | R$2.81 | 5.62 | R$12.46
Lucas Mariano
2 | Transistores MOSFET IRFZ34 | R$2.10 | R$4.20
2 | Transistores MOSFET IRF9530 | R$2.48 | R$4.96
2 | Amplificador LM386 | R$0.93 | R$1.86
1 | Amplificador TDA2822M | R$1.20 | R$1.20
3 | Placa Fenolite 10x15 Cm | R$3.77 | R$11.31
 |  |  |  | Valor a Pagar, Lucas C\ Frete
 |  | Sub Total | R$23.53 | R$30.37
 | TOTAL A PAGAR | R$126.99
 | TOTAL NO SITE | R$126.92
 | Frete | R$20.51
 | TOTAL C\Frete | R$147.43 |  | R$147.50
 | Frete Dividio para 3 | 6.836666667

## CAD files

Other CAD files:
Desenho2.dwg

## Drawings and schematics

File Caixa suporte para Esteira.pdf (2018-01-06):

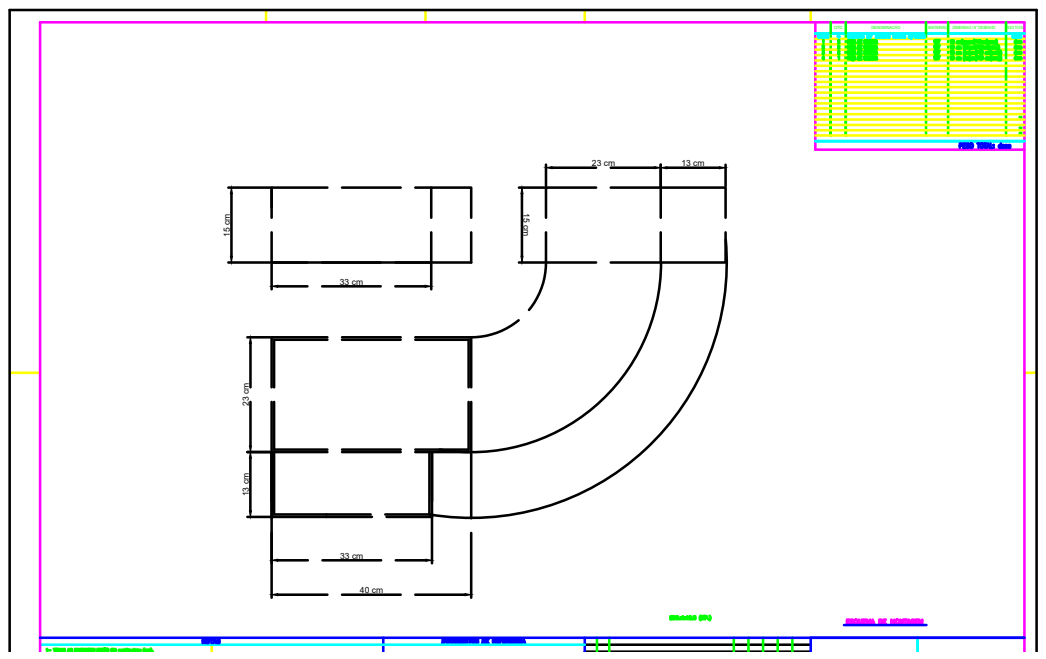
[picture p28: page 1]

QTD. DENOMINACAO MATERIAL DIMENSAO / N° DESENHO | PESO TOTAL

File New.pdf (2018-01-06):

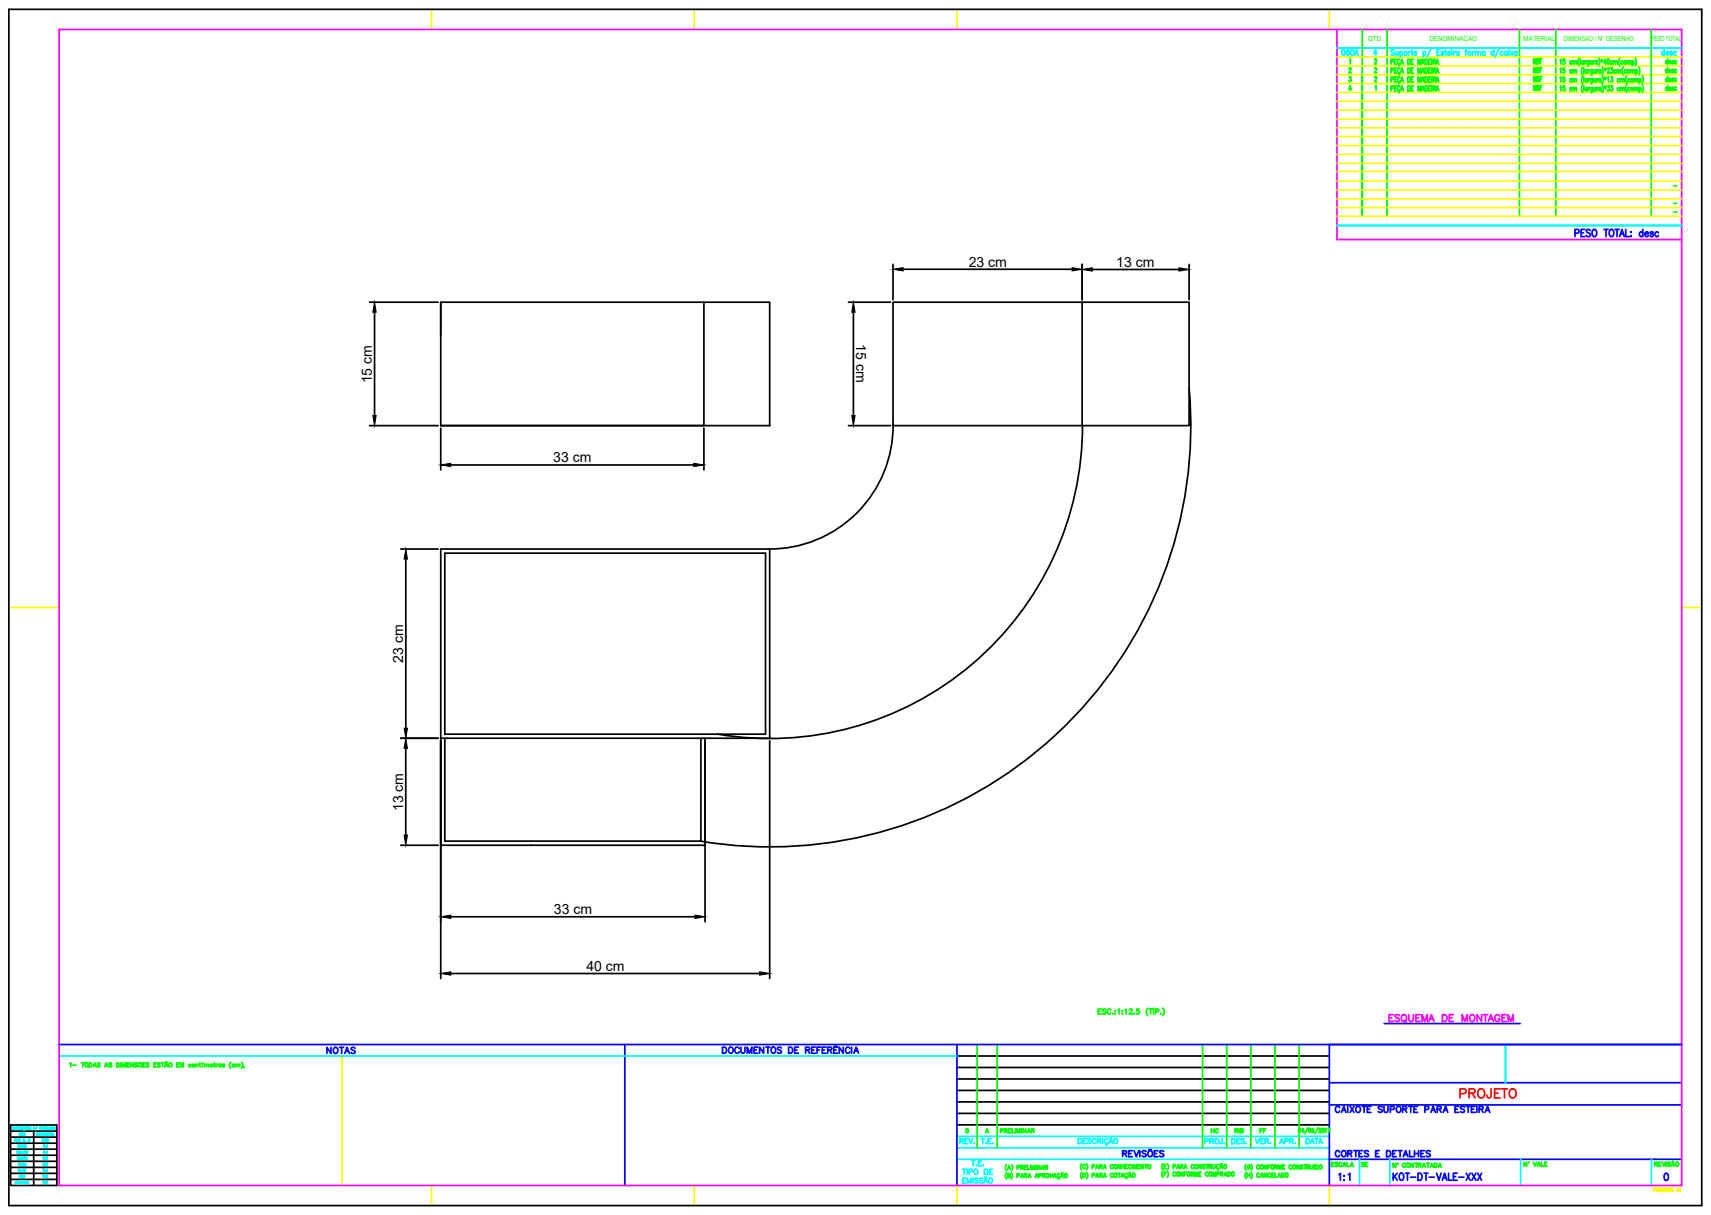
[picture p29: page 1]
QTD.; DENOMINACAO; MATERIAL; DIMENSAO / N° DESENHO; PESO TOTAL

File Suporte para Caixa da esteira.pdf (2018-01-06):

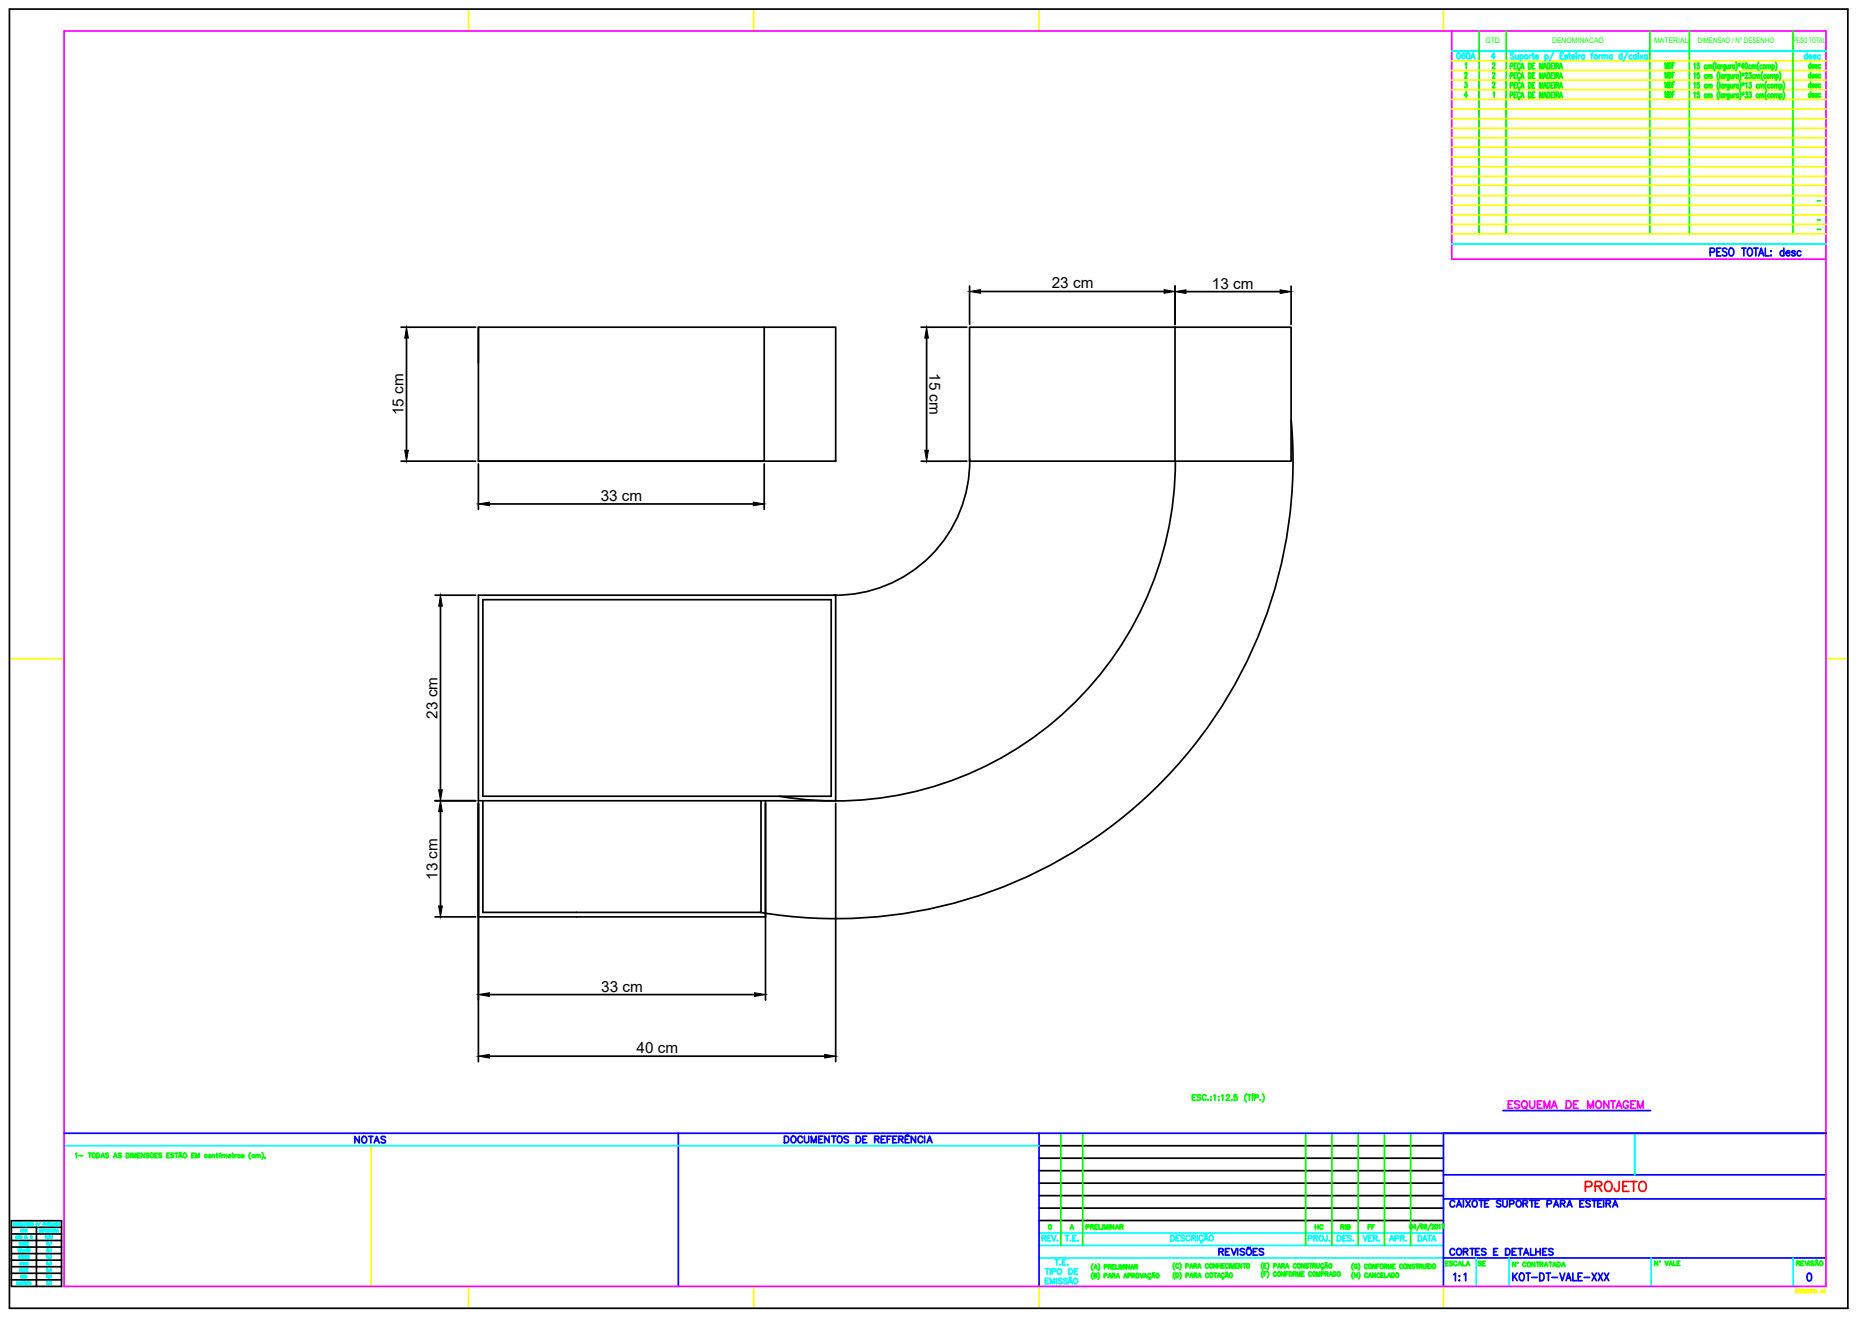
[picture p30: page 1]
QTD.; DENOMINACAO; MATERIAL; DIMENSAO / N° DESENHO; PESO TOTAL

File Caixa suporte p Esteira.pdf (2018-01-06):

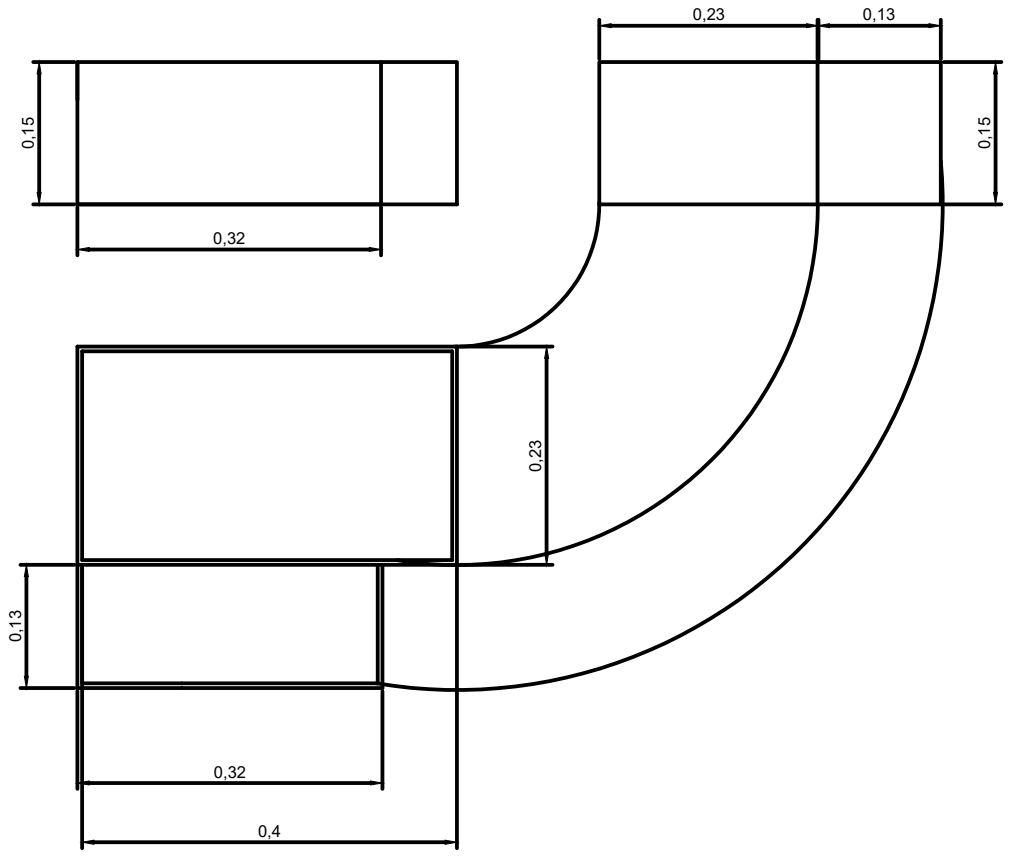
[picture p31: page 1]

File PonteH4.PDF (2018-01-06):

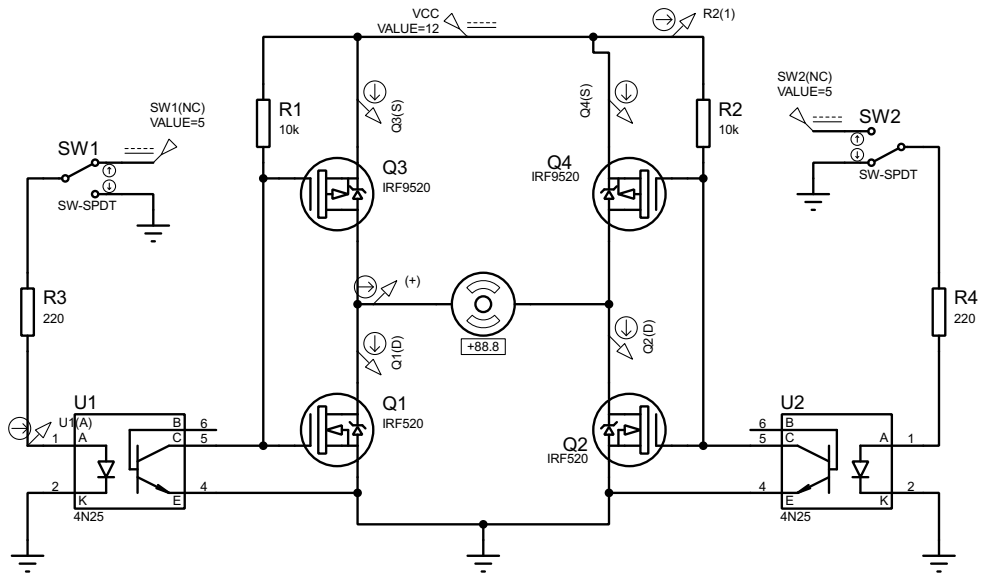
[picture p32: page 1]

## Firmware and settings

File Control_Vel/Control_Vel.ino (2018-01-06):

const int potenciometro = A0; // Variavél que especifica o pino analógico de leitura do potenciometro 
int valor;      // Variavel que recebe o valor a ser lido do potenciometro 
int velocidade;   // mapeia a velocidade lida do potenciometro para um valor de 0 a 255, isto ocorre porque a saida digital so aceita valores de 0 a 255 
                 // no qual 255 é tamanho maximo de bits que um valor pode ser representado em binário


void setup(){
  pinMode(2,OUTPUT);  //define o pino digital 2 - PWM- do arduino como porta de saída - (OUTPUT) para a saida da velocidade do motor lida do potenciometro
}

void loop(){


valor = analogRead(potenciometro); //lê do arduino o valor do potenciometro 
velocidade = map(valor, 0, 1023, 0, 255); //mapeia de 0 a 255

acionaMotor(velocidade); //aciona o motor com a velocidade lida. 

}
     

//procedimento para acionamento do motor
void acionaMotor(int velocidade){
 analogWrite(2,velocidade); 
}
